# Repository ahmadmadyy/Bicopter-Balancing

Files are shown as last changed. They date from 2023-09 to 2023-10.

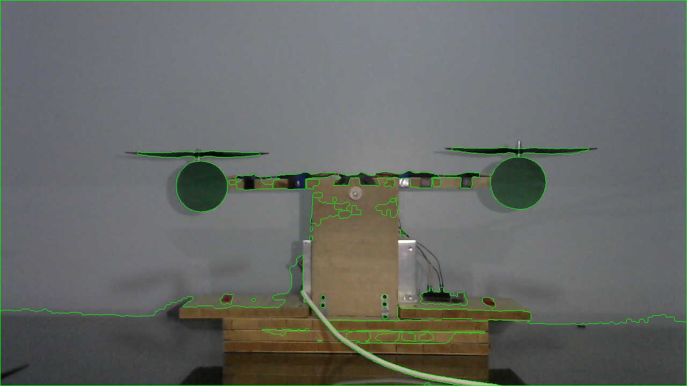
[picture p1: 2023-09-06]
Open Loop Tests/Tests on Camera and PC/Images/WATERSHED Segmentation.jpg

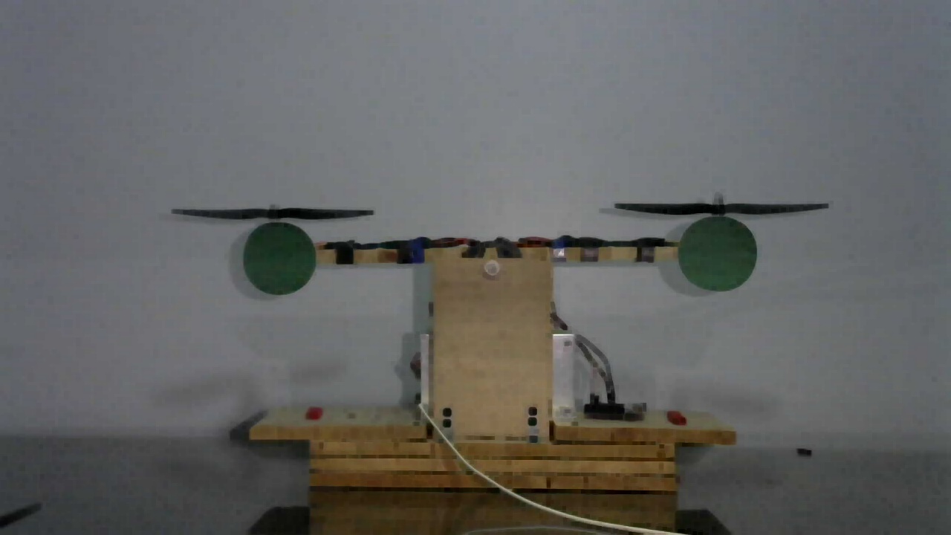
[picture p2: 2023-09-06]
Open Loop Tests/Tests on Camera and PC/Images/Erosion.jpg

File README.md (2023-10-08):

# Bicopter-Balancing
## A bicopter that uses a camera sensor and a computer vision algorithm in Python on an embedded Raspberry Pi 4 to balance a beam horizontally by actuating 2 BLDC Motors

#### The hardware consists of 2 BLDC Motors and a horizontal beam attached to their respective Electroic speed controllers(ESCs). After callibration, the 2 ESCs are connected to the raspberry pi 4, where the webcam camera sensor is connected, and using python and computer vision with some image processing techniques, the beam balanced.

#### In this repo, you can find the hardware design folder which contains all the Solidworks parts and assembly. In the open loops tests folder, you will find some python codes for applying image processing techniques on the captured images. In the closed loop folder, you will find the python codes for using the PID control on the raspberry pi. All technical detalis can be dound in the project report folder.

## Youtube Video:
Video (https://www.youtube.com/watch?v=bFz2ZuhfHQo)

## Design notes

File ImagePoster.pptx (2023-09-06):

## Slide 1

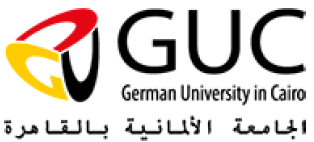
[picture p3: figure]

Image Processing for Mechatronics MCTR1010

Balancing a Brushless Bicopter using a Visual Sensor

Dr. Eng. Omar M. Shehata , Eng. Dalia M. Mahfouz, Eng. Mai Mira, MSc

Team Members:
Ahmed Mady 46-0798 ahmed.alimady@student.guc.edu.eg || Ahmed Yasser 46-12951 ahmed.yasser@student.guc.edu.eg ||Omar Mohsen 46-5023 omar.mohsen@student.guc.edu.eg Mostafa Kashaf 46-5456 mostafa.kashaf@student.guc.edu.eg || Mohamed Magdy 46-3493 mohamed.magdy@student.guc.edu.eg

Spring 2023

Abstract
The bicopter is a two-rotor aerial vehicle, characterized by its ability to maintain stable flight by actively adjusting the angle of its central bar horizontally. By leveraging the powerful computational capabilities and the versatility of the Raspberry Pi, the system achieves enhanced responsiveness and adaptability. The webcam captures images of the surrounding environment and processes them using image processing algorithms techniques such as edge detection is employed to identify the bicopter's central bar and determine its orientation relative to the horizontal plane. The integration of the Raspberry Pi and the webcam result in a robust and cost-effective solution for achieving self-balancing flight.

Results
Execution Time: On a Raspberry Pi 4B+, the average execution time of the code you provided is about 100 milliseconds. This means that the code can process one frame of video every 100 milliseconds. Accuracy: The accuracy of the code in detecting the angle of the bicopter is very high as the 2 motors never turn off but are always on and at varying speeds. Stability: The stability of the bi-copter was taken into consideration when designing the control law. Responsiveness: The responsiveness of the code to changes in the angle of the bicopter.

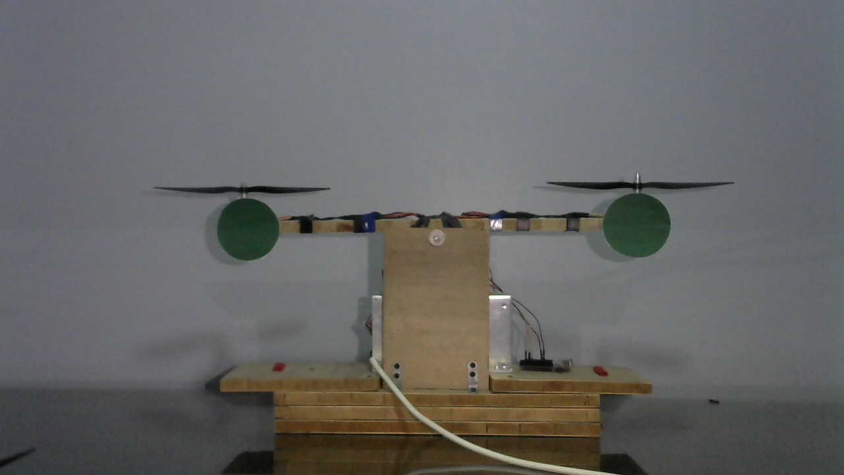
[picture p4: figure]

Methodology
To control the bicopter, a desired angle is inputted, and according to this angle, the speed of both motors is adjusted as they rotate in directions opposite to each other. Below each propeller, a colored circle is attached to track the error between the pitch and the desired angle using a visual sensor, the camera. The circles are of the color green and a threshold is applied to grab only the color needed. Then segmentation and edge detection were applied to track the circle and draw a line connecting both circles and measuring the angle. This measured error angle is then fed from the camera into the control loop as feedback and the correct speed is sent to the ESC of the two brush-less motors by the computer to achieve the desired angle.

Conclusion
The camera’s input is processed by the Raspberry Pi, which analyzes the images and extracts relevant features to estimate the bicopter’s position and orientation. This data is then fed into the PID control algorithm, which calculates the necessary adjustments to the bicopter’s motor speeds or control surfaces. The integration of these technologies enables autonomous or semi-autonomous flight of the bicopter. Overall, the combination of a camera, Raspberry Pi 4B+, and PID control offers a reliable and adaptable system for controlling a bicopter.

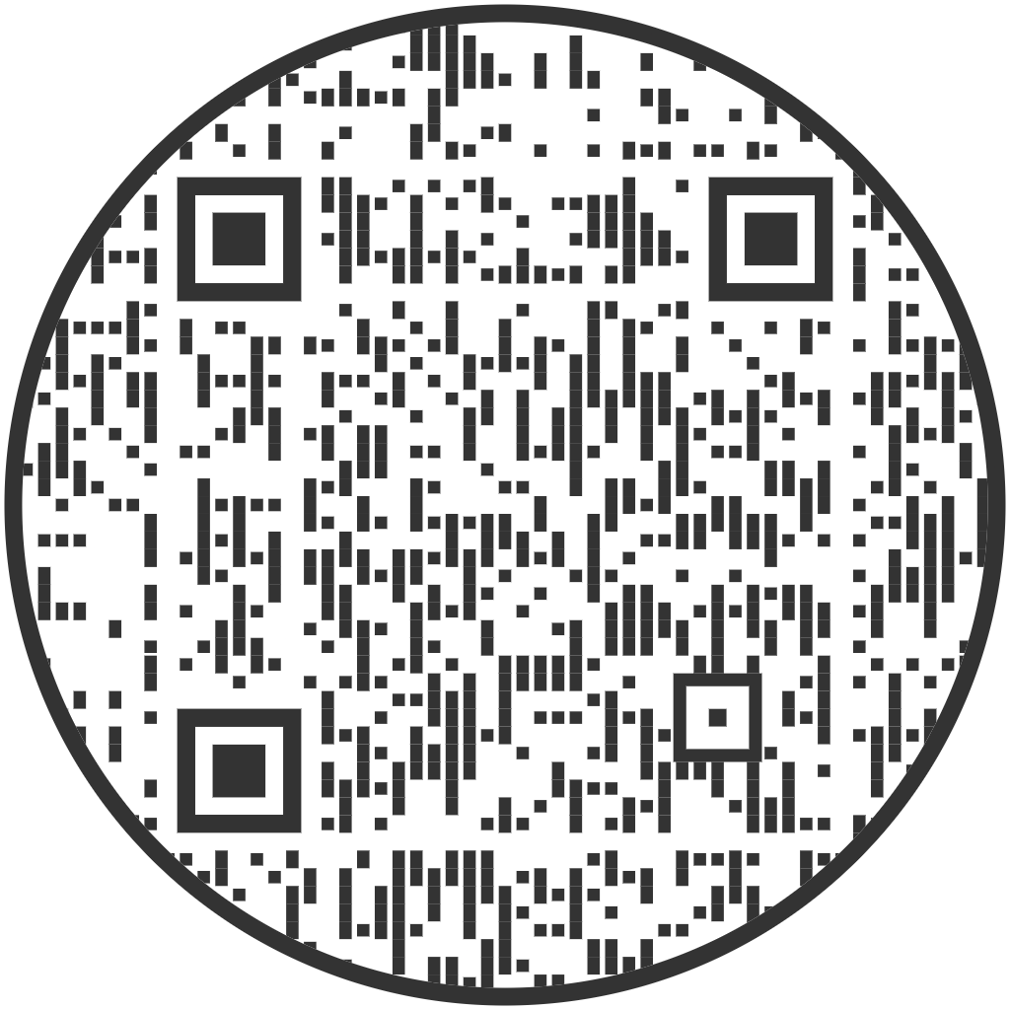
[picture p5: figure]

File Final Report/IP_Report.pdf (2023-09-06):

## Balancing a Brushless Bicopter using a Visual Sensor

Ahmed Mady, Ahmed Yasser, Omar Mohsen, Mostafa Kashaf, Mohammad Magdy

Abstract

The bicopter is a two-rotor aerial vehicle, characterized by its ability to maintain stable flight by actively adjusting the angle of its central bar horizontally. By leveraging the powerful computational capabilities and the versatility of the Raspberry Pi, the system achieves enhanced responsiveness and adaptability. The webcam captures images of the surrounding environment and processes them using image processing algorithms techniques such as edge detection is employed to identify the bicopter’s central bar and determine its orientation relative to the horizontal plane. The integration of the Raspberry Pi and the webcam result in a robust and cost-effective solution for achieving self-balancing flight.

I. INTRODUCTION
A flying vehicle is not a novel engineering product. Yet, the rapid growth of unmanned aerial vehicles (UAVs) has made a research on the subject of flying vehicles a global hotspot today. One of the difficult difficulties has been reducing the number of rotors in a rotor-type UAV. One of the examples with only two rotors is the bicopter. As compared to other typical rotor-type UAVs with more rotors, it has a longer flight time. A reduction in the number of rotors can reduce unit time power demand and, as a result, improve flight time. However, because of the complexity of the mathematical dynamics model, controlling a bicopter system is not a simple process. To maintain the desired trajectory, the designed controller must be capable of stabilizing the bicopter with an acceptable response time while also overcoming the oscillation effect. To accurately stabilize the bicopter, a camera is used to find the angle of inclination of the birotor.

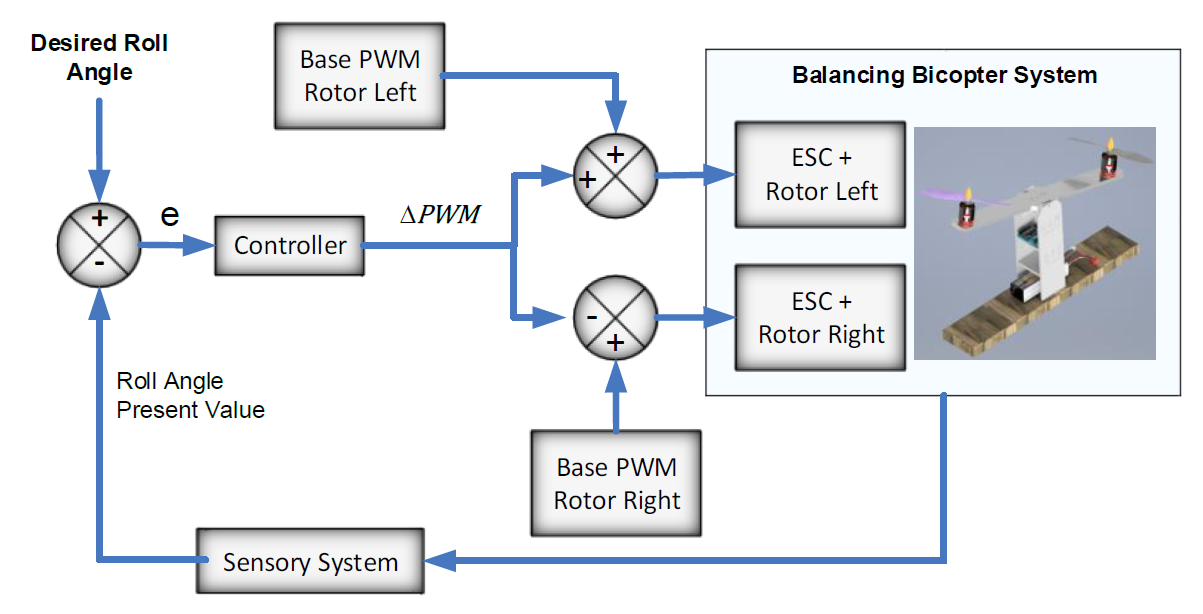
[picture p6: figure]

Fig. 1. The flow diagram of the system

II. METHODOLOGY

A. Workflow
To control the bicopter, a desired angle is inputted, and according to this angle, the speed of both motors is adjusted as they rotate in directions opposite to each other. Below each propeller, a colored circle is attached to track the error between the pitch and the desired angle using a visual sensor, the camera. The circles will be of the color blue and a threshold will be applied to grab only the color needed. Then segmentation and edge detection will be applied to track the circle and draw a line connecting both and measuring the angle. This measured error angle is then fed from the camera into the control loop as feedback and the correct speed is sent to the ESC by the computer of the two brush-less motors to achieve the required angle desired. Figure 1 shows the flow diagram of the bicopter system. The sensory system is the Sony Widescreen HD 720p webcam.
B. Components
C. Circuit Design
The schematic circuit diagram of the birotor system is shown in Figure 3 which consists of the two brushless motors, the two ESCs, the Arduino, and the power source. The camera is the feedback element and is connected to the computer directly. The flow of data, Figure ?? is first from the camera to the computer which applies the image processing algorithm which calculates the angle of the bicopter which is then sent to the Arduino using a USB connection and into the control loop. The Arduino then calculates the required speed of the motors.

TABLE I

LIST OF COMPONENTS

Component | Number | Purchase Location | Price
Raspberry Pi 4B | 1 | Future Electronics | 3370E£
Electronic Speed Controllers | 2 | Future Electronics | 205E£
Brushless Motor | 2 | Amazon Eg | 388E£
Propeller | 2 | Future Electronics | 150E£
12V 20A Power Source | 1 | Amazon Eg | 220E£
Sony Webcam | 1 | Amazon Eg | 599E£

Fig. 2. Solidworks Assembly 1

D. Image Processing

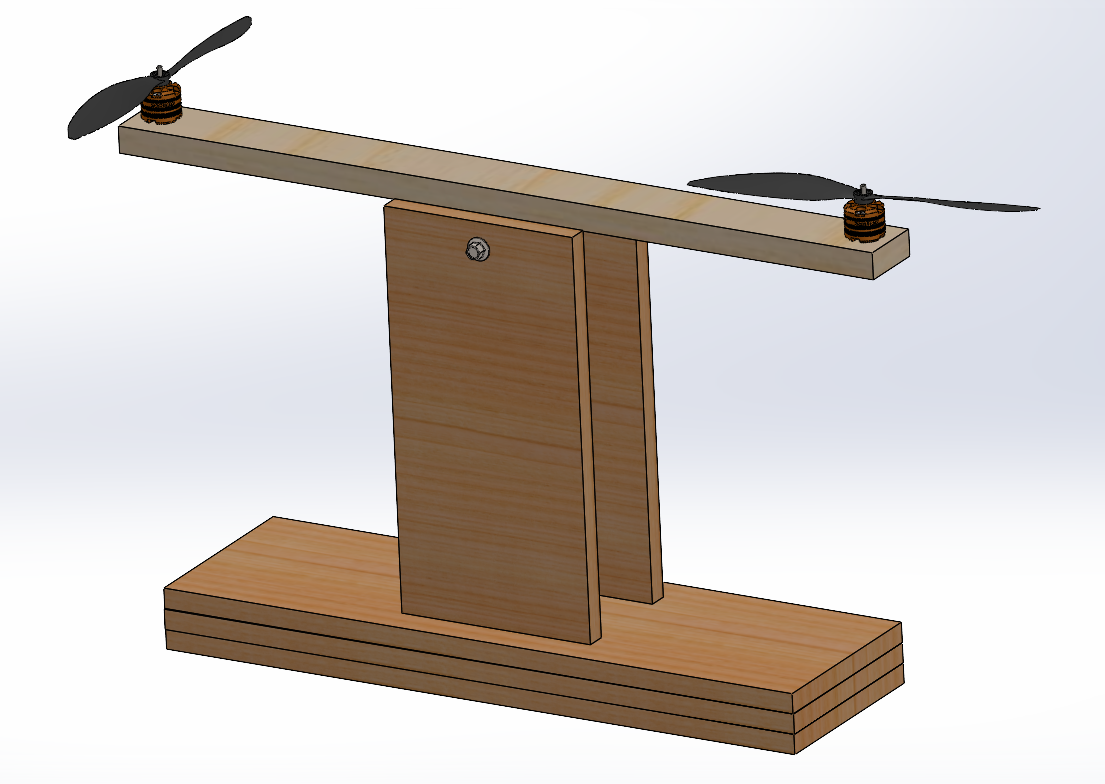
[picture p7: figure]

Image processing is the process of converting an image to a digital format and then executing various operations on it to extract valuable information. When specific specified signal processing methods are used, the image processing system typically interprets all images as 2D signals. The figure below 4 depicts the original photo taken by the camera prior to any image processing. Image processing tasks performed were translation and scaling, then converting the normal RBG image to LAB and HSV color spaces then grayscale where contrast enhancement and darkening were applied.
1) Intensity Level Transformation

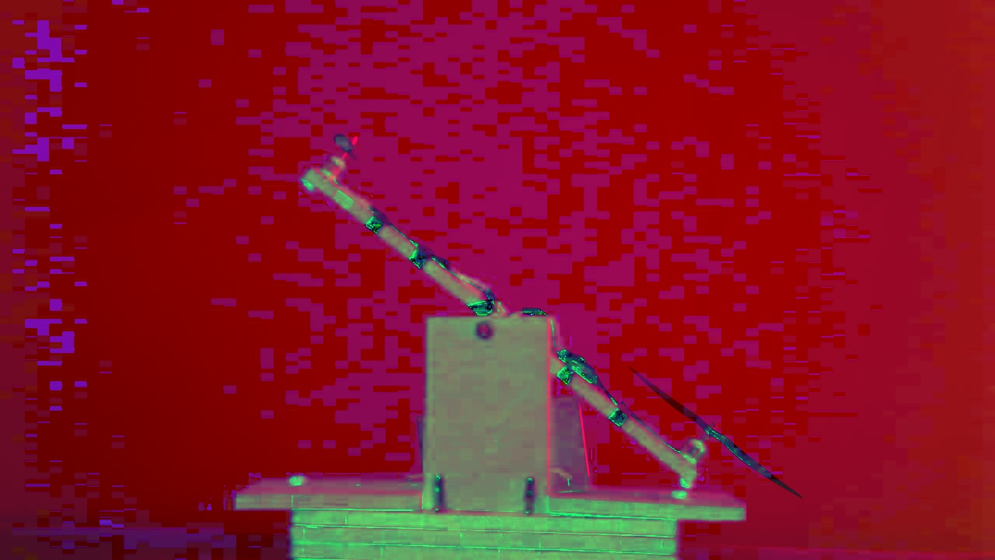
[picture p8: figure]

Fig. 5. The Image After Applying HSV Color Space

2) Morphological Operations
Morphological operations are a set of operations that process images based on shapes. They apply a structuring element to an input image and generate an output image.

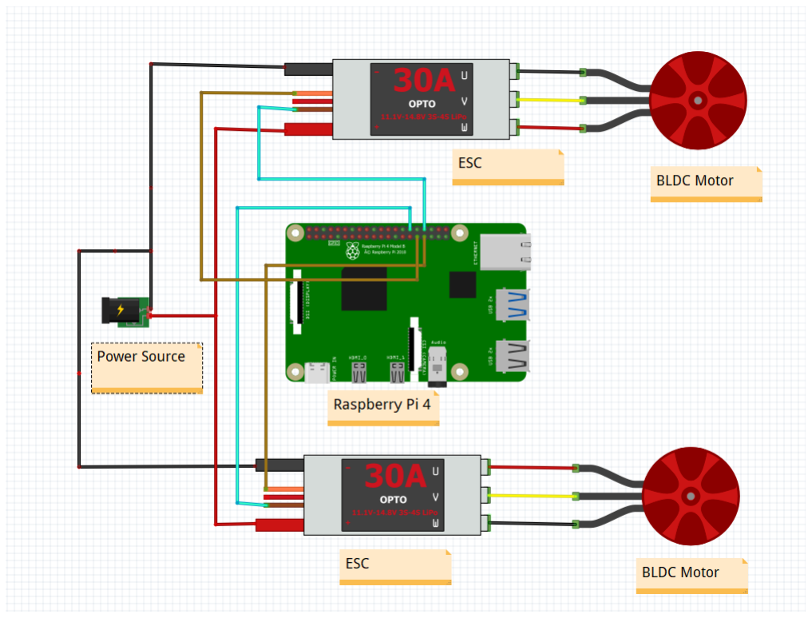
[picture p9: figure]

Fig. 3. Circuit diagram of the birotor system

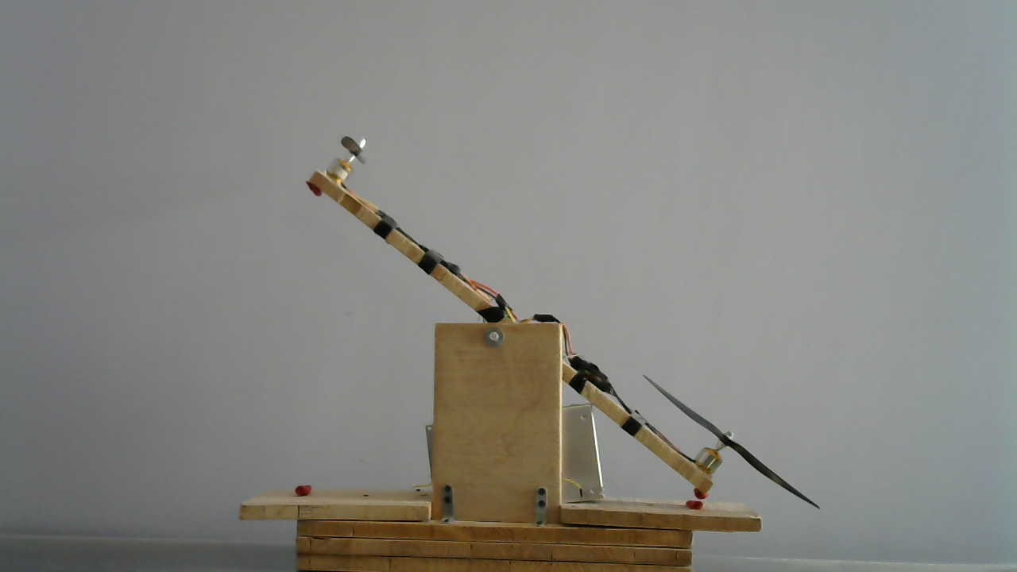
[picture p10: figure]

Fig. 4. Orignal Image before any transformations


Fig. 6. The original image after adding colored figures, circles, under each motor

Next, erosion and dilation are applied. Basics of Erosion: Erodes away the boundaries of the foreground object, Used to diminish the features of an image. Basics of dilation: Increases the object area, Used to accentuate features. Both are applied using a 5 x 5 kernel.


Fig. 7. The image after applying erosion using a 5 x 5 kernel

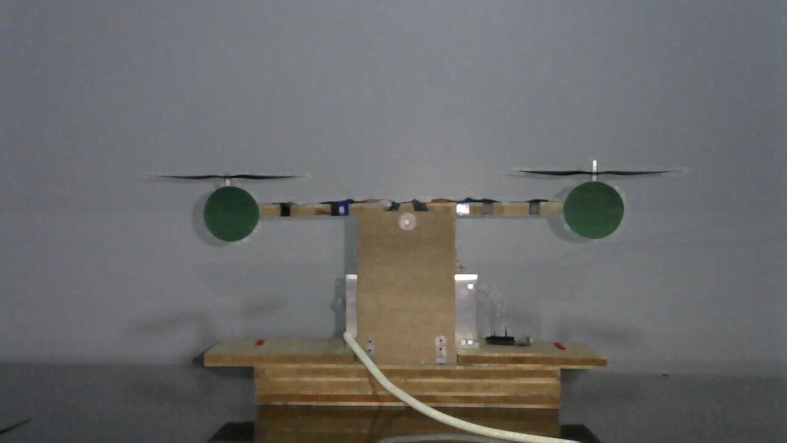
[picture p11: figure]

Fig. 8. The image after applying dilation using a 5 x 5 kernel

3) Edge Detection Edge detection is an image processing technique for finding the boundaries of objects within images. It works by detecting discontinuities in brightness. In this paper, edge detection is implemented using different methods applied on the, 5 x 5 Gaussian blurred image:
a) Canny Edge Detection

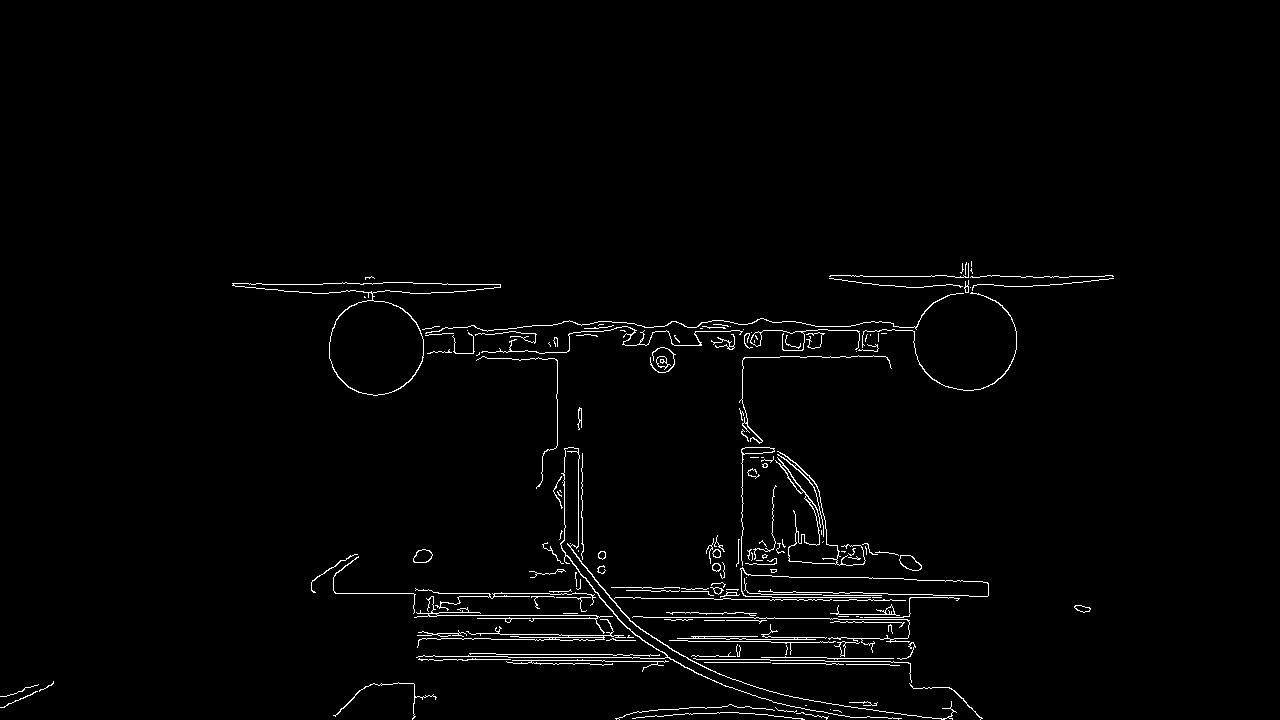
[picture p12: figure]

Fig. 9. The image after Canny edge detection using a threshold range 0 to 60

4) Segmentation
a) Color Segmentation The first type of segmentation applied was to color segment the green circle which will be used later for angle calculation.

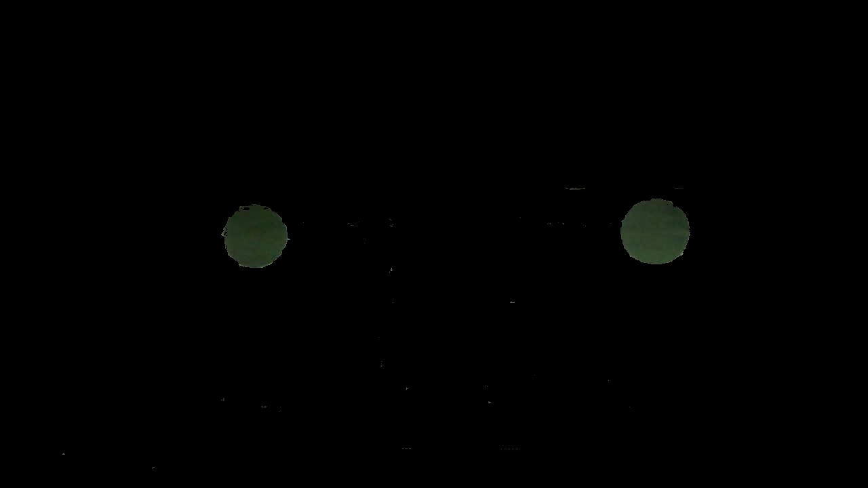
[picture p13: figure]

Fig. 10. The image after applying the green segmentation

b) Watershed Algorithm The watershed algorithm is used for segmentation in some complex images if we apply simple thresholding and contour detection then will not be able to give proper results. The watershed algorithm is based on extracting sure background and foreground and then using markers will make a watershed run and detect the exact boundaries. This algorithm generally helps in detecting touching and overlapping objects in the image. For markers, it can be user-defined like manually clicking and getting the coordinates and also using some defined algorithms such as thresholding or any morphological operations. Due to the presence of noise, we can’t apply watershed algorithms directly.


Fig. 11. The image after applying the watershed algorithm

E. Control
The dynamical equation is shown in Equation 1:

˙
˙θb =

M2 − M1 ∗ g ∗

L
2 − b

˙
θb − a

˙ θb(ωm2 + ωm1
) + 0.00125L ∗ (ωm2 + ωm1

)
MomentofInertia | (1)

T ransferF unction :

0.6126s

3 − 1.359s

2 + 28.81s + 5.315
s

4 + 2.27s

3 + 19.89s

2 + 14.84s + 2.74

(2)

After manually tuning the PID the final values reached were:

kp = 1, ki = 2, kd = 0.3 | (3)

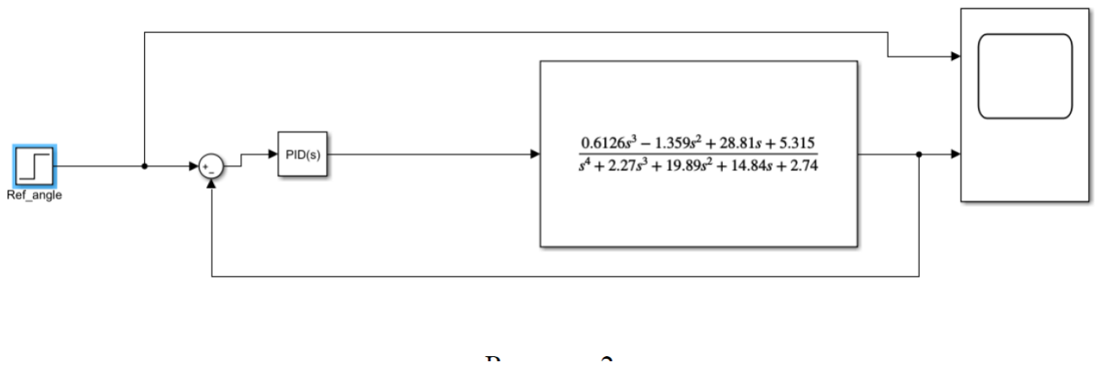
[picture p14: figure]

Fig. 12. SIMULINK simulation of the transfer function

a) Closed Loop Response In this section, a simple closed loop is tested. Python communicates with Arduino to send a control action to the 2 BLDC motors based on the image processing signal by establishing a serial communication. First in the image processing code in python, the frame captures from the external camera then converts the frame into gray-scale. After converting, numpy mean method is used to calculate the average of the intensity levels of the pixels in the image. If the pixels have a mean higher than 100, also called a bright frame, the left motor is actuated based on a signal given from python to the Arduino. If the mean is less than 50, dark frame, the right motor is actuated.
F. Actuation
At the beginning of the code, the libraries are imported. Then, the ranges of green color are HSV are defined from low to the max values based on trial and error which then applies a mask to detect only green color on the video capture frame which in turn is used to detect only the largest 2 circles only of green colors. The centers of the circles are used then to calculate the slope of the bi copter bar which is our error signal. This error signal is taken as input to the PID controller and then taken as input to the PWM output to the motor.

III. RESULTS
The results of this study show that it is possible to balance a bicopter around a zero angle using a camera and a Raspberry Pi. The system was able to maintain a stable hover for up to 30 seconds, even in the presence of disturbances. The system was also able to track the moving target circles, such as a person’s head, and maintain a balancing angle.
A. KPIs
Execution Time: On a Raspberry Pi 4B+, the average execution time of the code you provided is about 100 milliseconds. This means that the code can process one frame of video every 100 milliseconds. Accuracy: The accuracy of the code in detecting the angle of the bicopter is very high as the 2 motors never turn off but are always on and at varying speeds. Stability: The stability of the bi-copter was taken into consideration when designing the control law. Responsiveness: The responsiveness of the code to changes in the angle of the by-copter.

IV. CONCLUSION
In conclusion, the utilization of a camera and Raspberry Pi 4B+ in combination with PID control provides an effective solution for controlling a bicopter. By leveraging the camera’s ability to capture real-time images and the Raspberry Pi’s processing power, the system can extract essential information about the bicopter’s orientation and position. This information is then used to calculate appropriate control signals using PID control algorithms, ensuring stable and precise flight.
The camera’s input is processed by the Raspberry Pi, which analyzes the images and extracts relevant features to estimate the bicopter’s position and orientation. This data is then fed into the PID control algorithm, which calculates the necessary adjustments to the bicopter’s motor speeds or control surfaces.
PID control provides a robust and widely used method for adjusting control signals based on the error between desired and measured values. It continuously evaluates and adjusts the output to minimize this error, resulting in smooth and accurate control of the bicopter.
The integration of these technologies enables autonomous or semi-autonomous flight of the bicopter. It opens up possi-bilities for various applications, such as aerial surveillance, monitoring, and inspection tasks. Additionally, the flexibility of the Raspberry Pi platform allows for easy customization and expansion, facilitating the implementation of advanced features and functionalities.
Overall, the combination of a camera, Raspberry Pi 4B+, and PID control offers a reliable and adaptable system for controlling a bicopter. It represents a promising avenue for further exploration and development in the field of unmanned aerial vehicles and autonomous systems.

V. VIDEOS

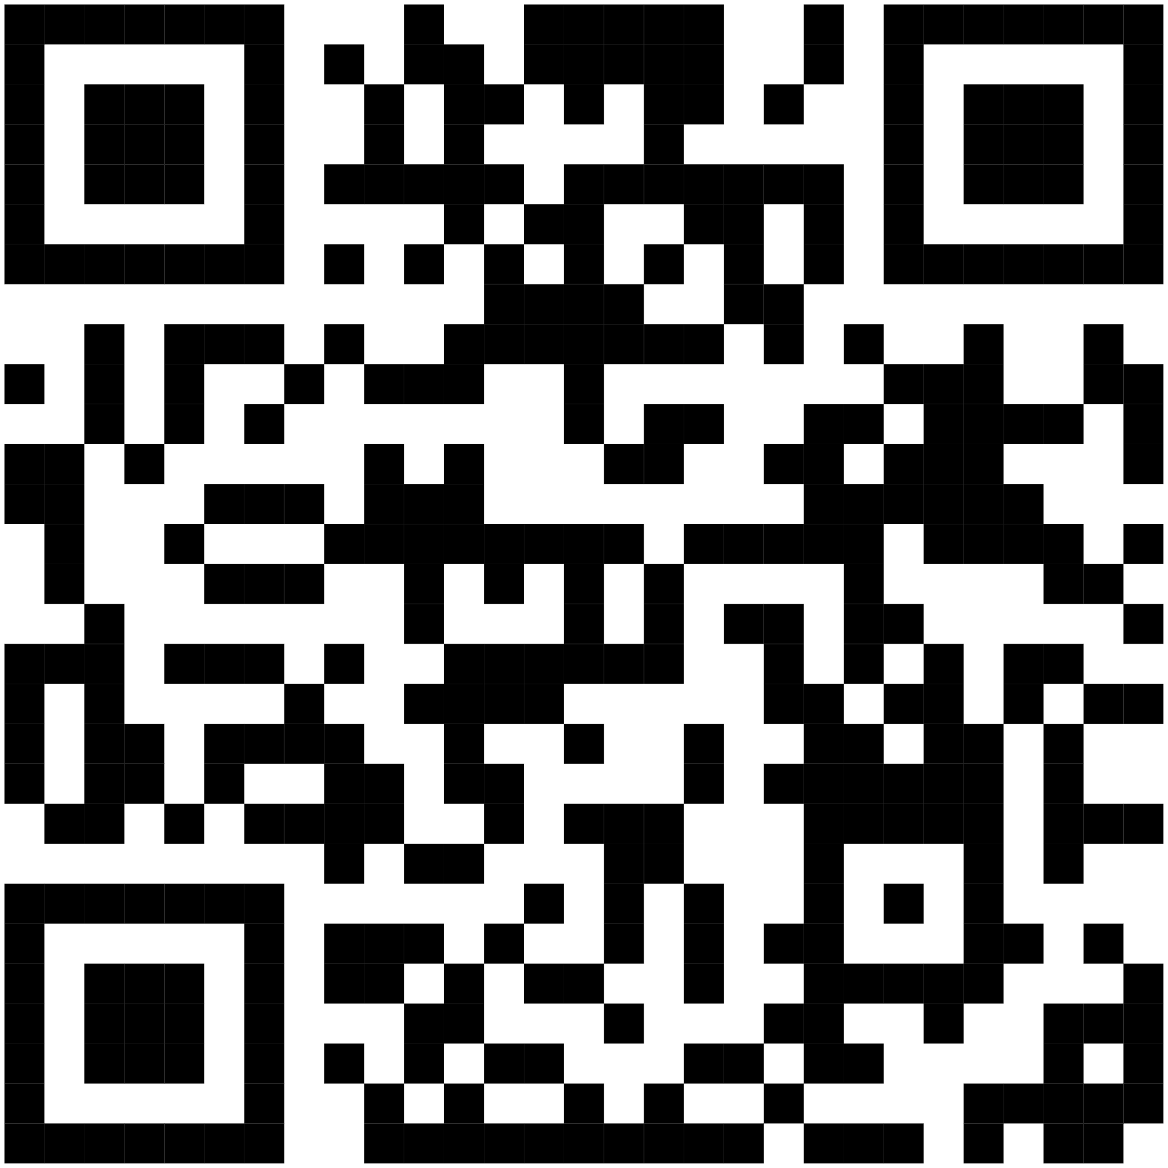
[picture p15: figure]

Fig. 13. QR Code containing the videos of the hardware

REFERENCES

[1] Apriaskar, E., Fahmizal, F., Salim, N. A., & Prastiyanto, D. (2019). Performance Evaluation of Balancing Bicopter using P, PI, and PID Controller. Jurnal Teknik Elektro, 11(2), 44-49.
[2] Siddhartha, K. (2018). A novel bi-rotor configuration and its control. IFAC-PapersOnLine, 51(1), 456-461.
[3] Qin, Y., Xu, W., Lee, A., & Zhang, F. (2020). Gemini: A compact yet efficient bi-copter uav for indoor applications. IEEE Robotics and Automation Letters, 5(2), 3213-3220.
[4] Jain, P., & Sangwan, V. (2020, July). Generation and Control of Impulsive Forces by a Planar Bi-Rotor Aerial Vehicle through a Cable Suspended Mass. In 2020 IEEE/ASME International Conference on Advanced Intelligent Mechatronics (AIM) (pp. 868-873). IEEE.
[5] Li, Y., Qin, Y., Xu, W., & Zhang, F. (2020, July). Modeling, identification, and control of non-minimum phase dynamics of bi-copter uavs. In 2020 IEEE/ASME International Conference on Advanced Intelligent Mechatronics (AIM) (pp. 1249-1255). IEEE.
[6] Ugurlu, H. ˘

˙I. (2019). A Comparative Study of learning-based control policies and conventional controllers on 2D bi-rotor platform with tail assistance (Master’s thesis, Middle East Technical University).
[7] Taherinezhad, M., Ramirez-Serrano, A., & Abedini, A. (2022). Robust trajectory-tracking for a bi-copter drone using indi: A gain tuning multi-objective approach. Robotics, 11(5), 86.
[8]

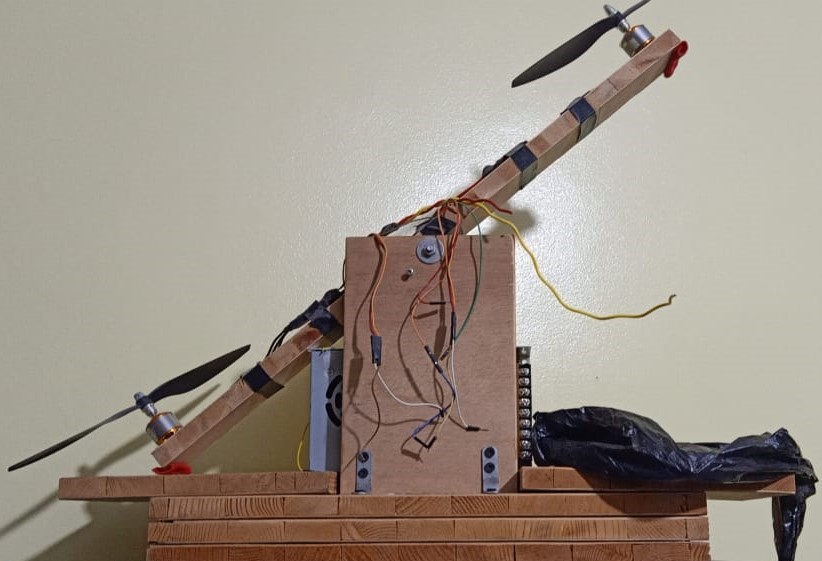
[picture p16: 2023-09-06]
Open Loop Tests/Pics/Hardware.jpg

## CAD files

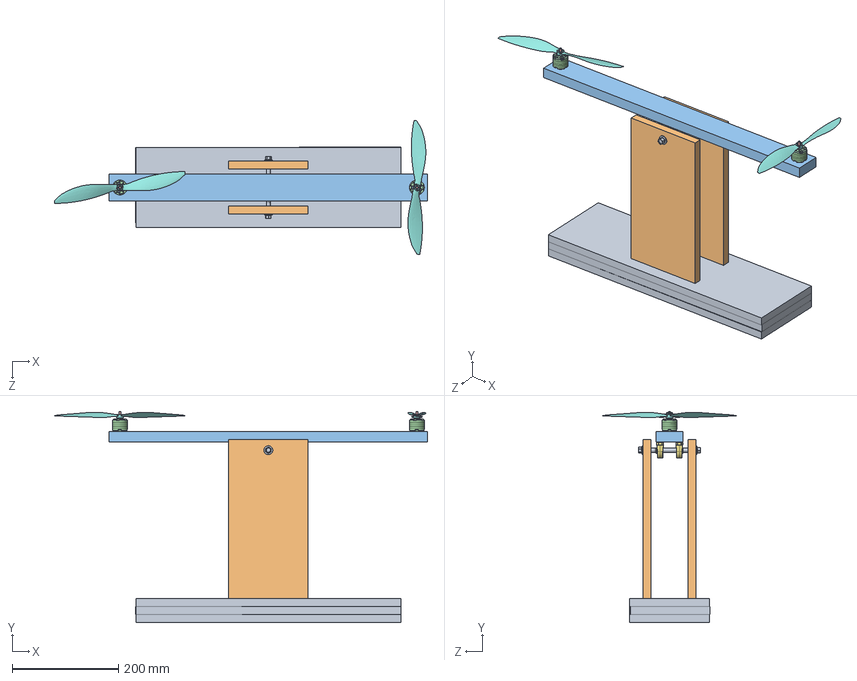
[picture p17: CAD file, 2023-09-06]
Hardware Design/Bicopter Assembly.SLDASM
703.2 x 398.0 x 253.4 mm
Base x 3
Front and Back x 2
Bar
ROTOR x 4
bldc motor shaft x 2
radial ball bearing_68_skf x 4
Bearing (KP08) x 2
10x4.7-clockwise-propeller x 2
indented hex flange head machine screw_am x 2

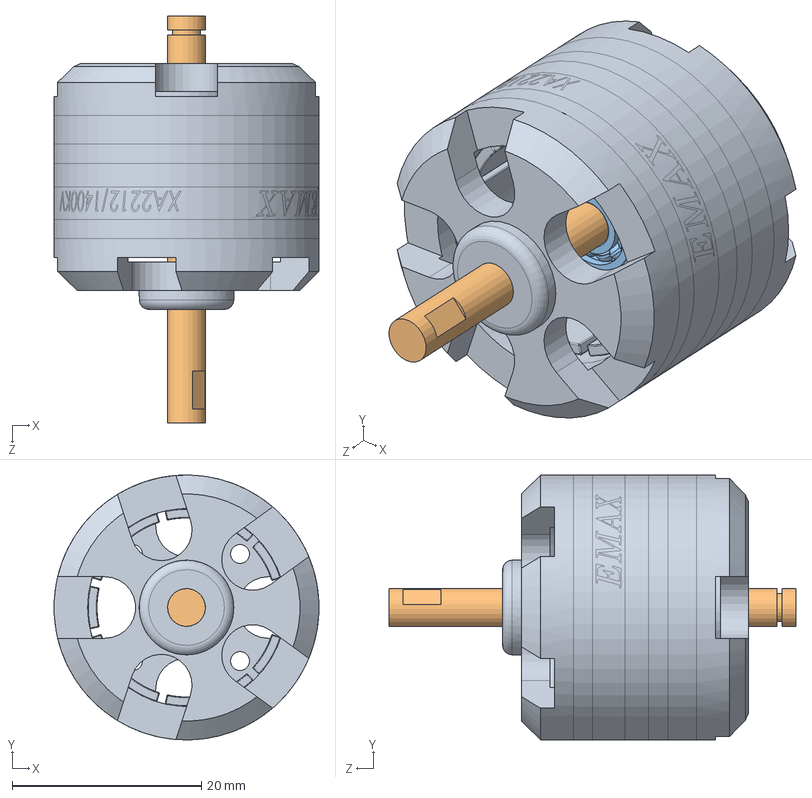
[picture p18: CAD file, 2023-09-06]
Hardware Design/a2212-brushless-dc-motor.SLDASM
28.0 x 28.0 x 43.0 mm
ROTOR x 2
bldc motor shaft
radial ball bearing_68_skf x 2

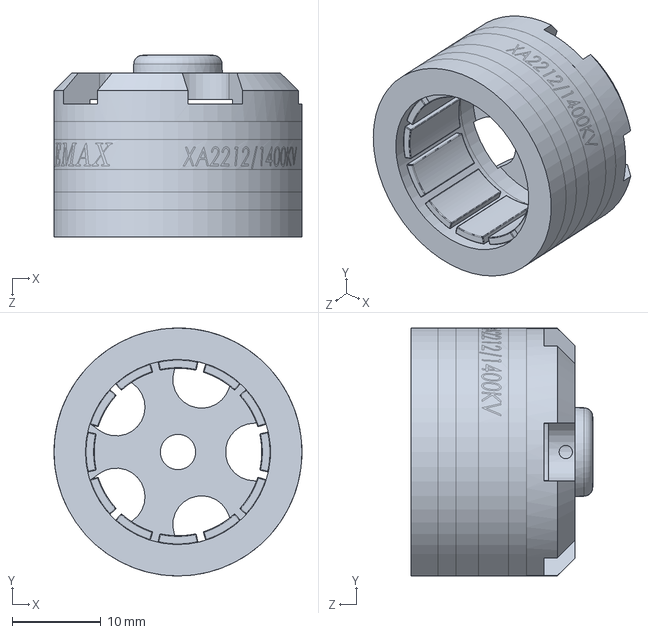
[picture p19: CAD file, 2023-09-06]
Hardware Design/ROTOR.SLDPRT
28.0 x 28.0 x 20.5 mm

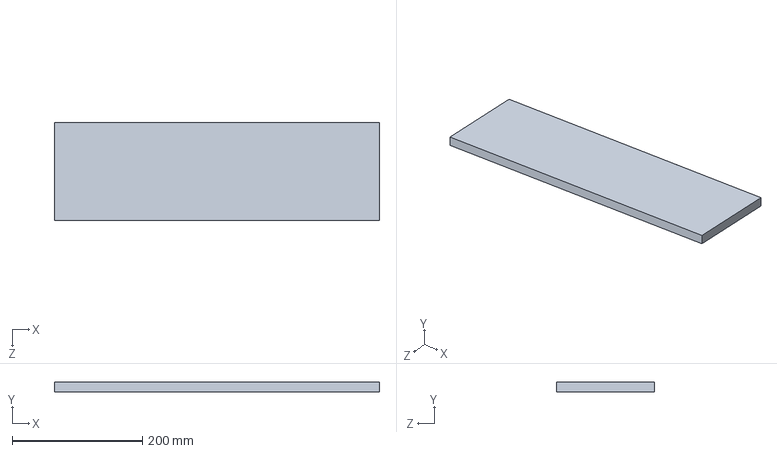
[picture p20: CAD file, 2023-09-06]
Hardware Design/Base.SLDPRT
500.0 x 15.0 x 150.0 mm

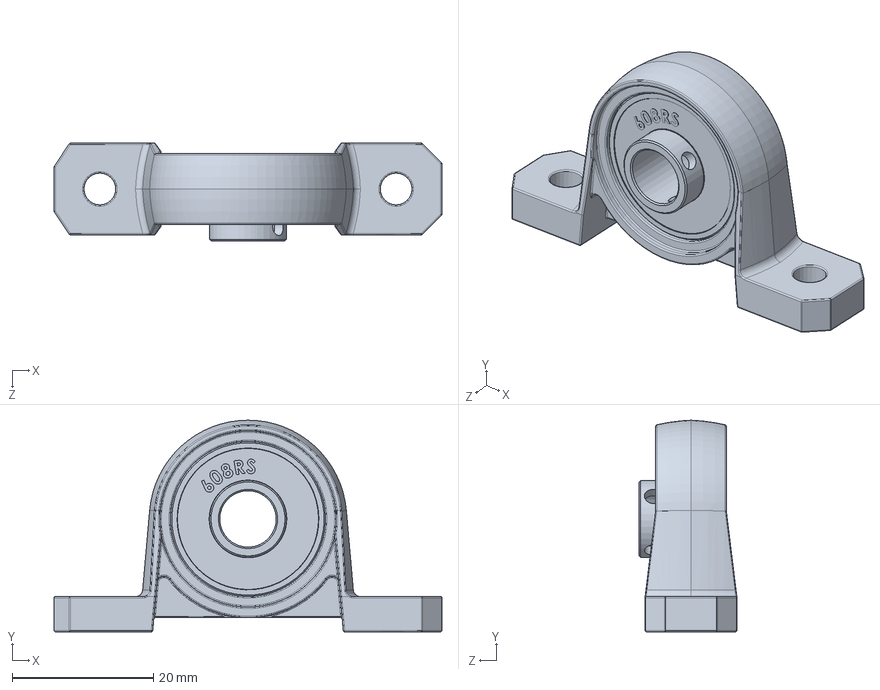
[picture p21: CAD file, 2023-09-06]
Hardware Design/Bearing (KP08).SLDPRT
55.0 x 30.0 x 13.9 mm

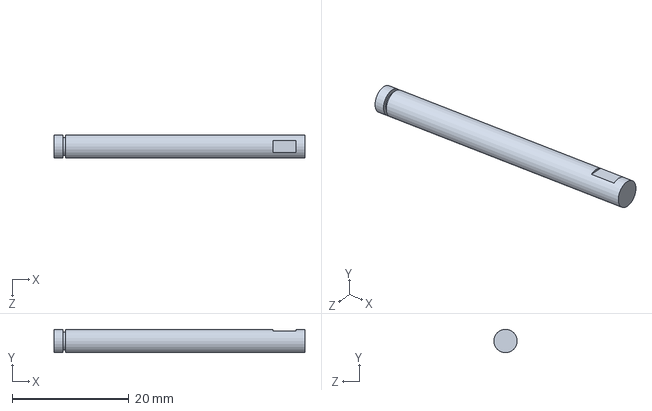
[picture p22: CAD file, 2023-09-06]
Hardware Design/bldc motor shaft.SLDPRT
43.0 x 4.00 x 4.00 mm

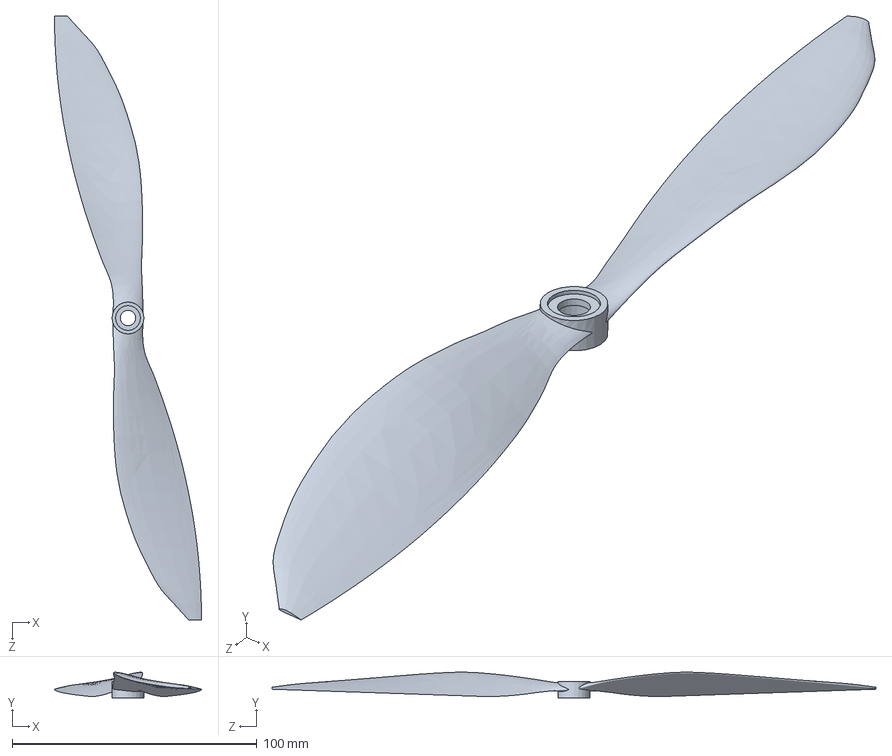
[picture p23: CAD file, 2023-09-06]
Hardware Design/10x4.7-clockwise-propeller.SLDPRT
60.0 x 10.5 x 246.4 mm

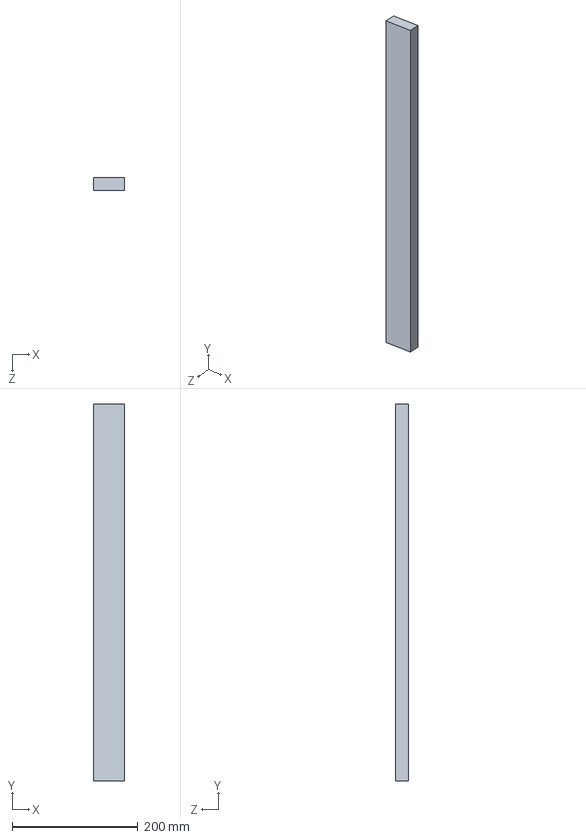
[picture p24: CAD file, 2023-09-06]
Hardware Design/Bar.SLDPRT
50.0 x 600.0 x 20.0 mm

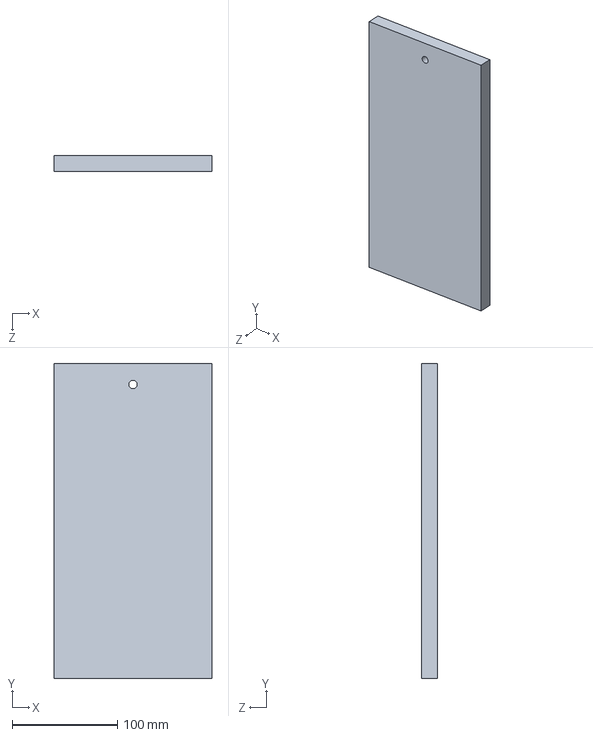
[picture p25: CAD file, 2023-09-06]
Hardware Design/Front and Back.SLDPRT
150.0 x 300.0 x 15.0 mm

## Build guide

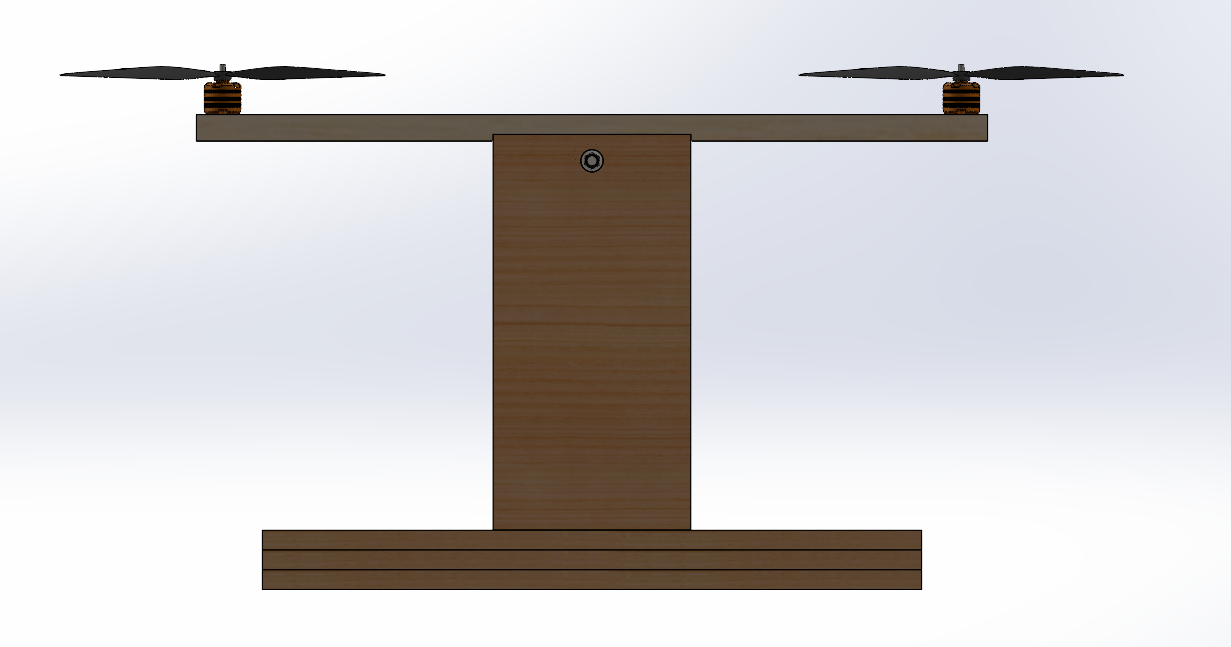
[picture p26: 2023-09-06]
Open Loop Tests/Pics/PICS/assembly2.png

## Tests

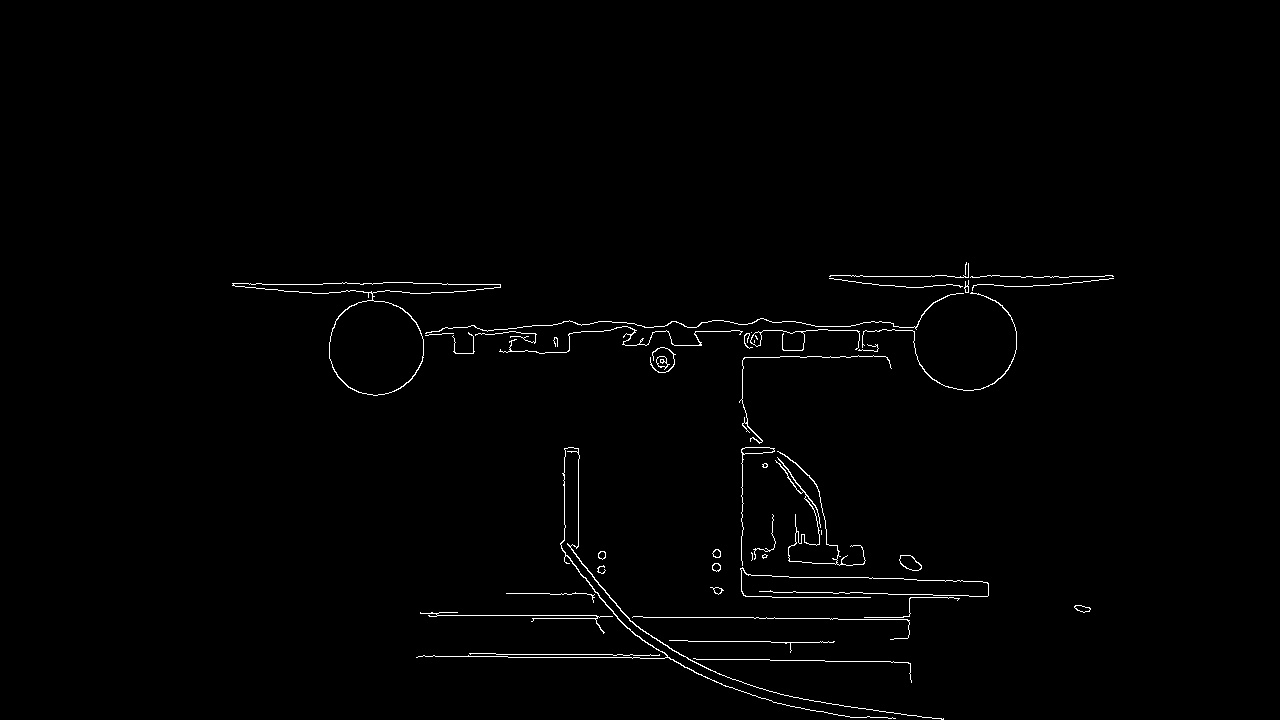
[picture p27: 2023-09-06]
Open Loop Tests/Tests on Camera and PC/Images/MidCanny.jpg

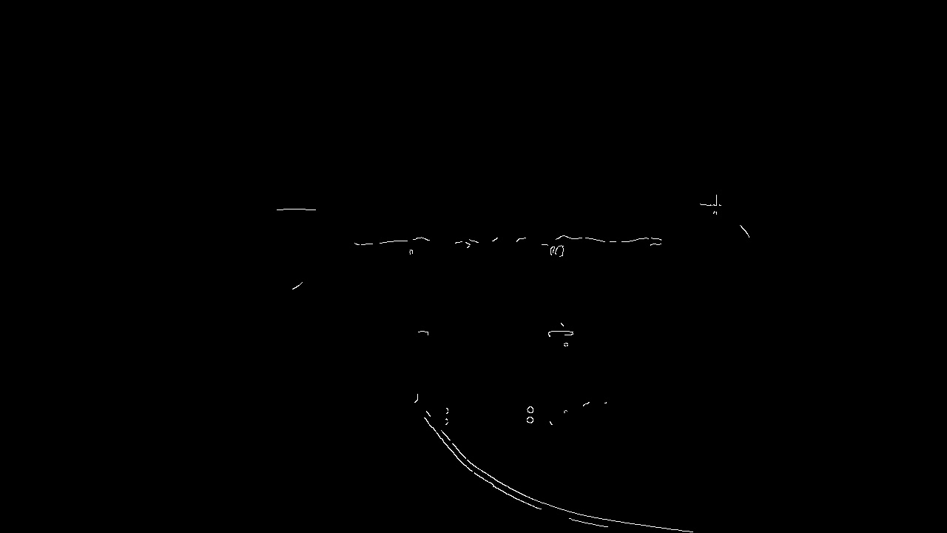
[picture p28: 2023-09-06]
Open Loop Tests/Tests on Camera and PC/Images/TightCanny.jpg

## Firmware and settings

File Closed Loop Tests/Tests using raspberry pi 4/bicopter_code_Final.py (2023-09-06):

#sudo killall pigpiod
import cv2
import os     #importing os library so as to communicate with the system
import time   #importing time library to make Rpi wait because its too impatient
sudoPassword='madypi'
command='killall pigpiod'
p=os.system('echo %s|sudo -S %s' % (sudoPassword, command))
os.system ("sudo pigpiod") #Launching GPIO library
#os.popen ("sudo -S %s"(sudo killall pigpiod),'w').write('madypi') #Launching GPIO library
time.sleep(1) # As i said it is too impatient and so if this delay is removed you will get an error
import pigpio #importing GPIO library
import numpy as np
import math

CURRENT_OPENCV_BUILD_VERSION = [4, 4, 0]
ESCR=19
#Connect the ESC in this GPIO pin
ESCL=13  #Connect the ESC in this GPIO pin

piR = pigpio.pi();
piL = pigpio.pi();
piR.set_servo_pulsewidth(ESCR, 1000)
piL.set_servo_pulsewidth(ESCL, 1000)
time.sleep(1)
cap = cv2.VideoCapture(0) # You may need to change the camera index depending on your system
startTime=0
throttle=1080
timee=time.time()

integralVal=0
e=0
loopDuration=0
prevDuration=0
u=0
prev_e=0

kp=0.88#3.3#0.83----0.88
ki=0.001
kd=0.55#1.7#0.36
global angle
angle=0.0
def image_Angle():
    ret, frame = cap.read()
     # Adaptive Thresholding
#     gray = cv2.cvtColor(frame, cv2.COLOR_BGR2GRAY)q
#     mean = np.mean(gray)
#     if mean < 100:
#         frame = cv2.convertScaleAbs(frame, alpha=70, beta=0)
#     elif mean > 200:
#         frame = cv2.convertScaleAbs(frame, alpha=0.5, beta=0)
    # Convert the frame to HSV color space
    hsv = cv2.cvtColor(frame, cv2.COLOR_BGR2HSV)
    # at a distance of 76 cm
    # White Lighting HSV
#     lower_green = np.array([40, 50, 50])
#     upper_green = np.array([80, 255, 255])
    # Yellow Lighting HSV
#    lower_green = np.array([90, 50, 50]) # 93
#    upper_green = np.array([100, 255, 255]) # 94
    lower_green = np.array([70, 60, 60])
    upper_green = np.array([80, 255, 255])
    
    # Threshold the HSV image to get only green colors
    mask = cv2.inRange(hsv, lower_green, upper_green)
    kernel = np.ones((9, 9), np.uint8)
    mask = cv2.morphologyEx(mask, cv2.MORPH_CLOSE, kernel)
    
    # Find contours in the binary image
    contours, hierarchy = cv2.findContours(mask, cv2.RETR_EXTERNAL, cv2.CHAIN_APPROX_SIMPLE)
    
    # Draw circles around the detected contours and calculate their centers
    centers = []
    for cnt in contours:
        (x, y), radius = cv2.minEnclosingCircle(cnt)
        diameter = radius * 2
        center = (int(x), int(y))
        if diameter >= 50: # Only consider circles with a diameter greater than or equal to 100 pixels
            cv2.circle(frame, center, int(radius), (0, 255, 0), 2)
            centers.append(center)
    
    # Calculate the angle between any two detected centers
    if len(centers) == 2:
        for i in range(len(centers)-1):
            for j in range(i+1, len(centers)):
                center1 = centers[i]
                center2 = centers[j]
                dx = center2[0] - center1[0]
                dy = center2[1] - center1[1]
                global angle
                angle = math.atan(dy/dx) * 180 / np.pi
                angle = round(angle,1)
                cv2.putText(frame, f"Angle: {angle:.2f} deg", (50, 50), cv2.FONT_HERSHEY_SIMPLEX, 1, (255, 0, 0), 2)


    
#     # Display the resulting frame
    scale_percent = 90# percent of original size
    width = int(frame.shape[1] * scale_percent / 100)
    height = int(frame.shape[0] * scale_percent / 100)
    dim = (width, height)

    resized = cv2.resize(frame, dim, interpolation = cv2.INTER_AREA)
#   gray = cv2.cvtColor(frame, cv2.COLOR_BGR2GRAY)
    
    cv2.imshow('frame', resized)
    return

def check_build_info():
    success = True

    print("OpenCV Version: {}".format(cv2.__version__))
    if (cv2.getVersionMajor() != CURRENT_OPENCV_BUILD_VERSION[0]) and (
            cv2.getVersionMinor() != CURRENT_OPENCV_BUILD_VERSION[1]) and (
            cv2.getVersionRevision() != CURRENT_OPENCV_BUILD_VERSION[2]):
        print("ERROR: OpenCV version is different than the expected.")
        success = False

    print("Available CPUs: ", cv2.getNumberOfCPUs())
    print("Available threads: ", cv2.getNumThreads())
    if cv2.getNumThreads() < cv2.getNumberOfCPUs():
        print("ERROR: TBB is not enabled.")
        success = False

    cv2.CPU_NEON = 100  # Value taken from OpenCV doc. CPU labels don't work correctly in Python
    print("Cpu NEON support: ", cv2.checkHardwareSupport(cv2.CPU_NEON))
    if not cv2.checkHardwareSupport(cv2.CPU_NEON):
        print("ERROR: NEON is not enabled.")
        success = False

    return success
if not check_build_info():
    print("FAIL: You are using OpenCV without NEON/TBB support enabled.")
    sys.exit(1)
print("SUCCESS: You are using latest OpenCV version, with NEON/TBB support enabled.")
i=0
desired=0
while True:
    image_Angle()

       prevDuration = timee
       timee = time.time()
       loopDuration = (timee - prevDuration)
       e = angle - desired

       if (-20 < e < 20):
           integralVal = integralVal + (ki * e)

       u = (kp * e) + integralVal + (kd * ((e - prev_e) / loopDuration))
        
       if (u < -1000):
           u = -1000

       if (u > 1000):
           u = 1000

       round(throttle,0)
       leftSignal = throttle + u+60
       rightSignal = throttle - u

       #Right
       if (rightSignal < 1090):
           rightSignal = 1090
        
       if (rightSignal > 2000):
           rightSignal = 2000
        
       #Left
       if (leftSignal < 1100):
           leftSignal = 1100
        
       if (leftSignal >= 2000):
           leftSignal = 2000
        
       piR.set_servo_pulsewidth(ESCR, rightSignal)
       piL.set_servo_pulsewidth(ESCL, leftSignal)
        
       prev_e = e
        
       if cv2.waitKey(1) == ord('q'):
           piR.set_servo_pulsewidth(ESCR, 1000)
           piL.set_servo_pulsewidth(ESCL, 1000)
           break
    
cap.release()
cv2.destroyAllWindows()

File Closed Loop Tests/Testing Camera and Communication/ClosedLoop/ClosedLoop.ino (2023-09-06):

#include <Servo.h>
Servo right_Esc;
Servo left_Esc;
float loopDuration, time, prevDuration;
float u, leftSignal, rightSignal, e, prev_e;
float integralVal=0;
double throttle=1030 ; 

void setup() {
  Serial.begin(115200);
  right_Esc.attach(3); 
  left_Esc.attach(5); 
  time = millis(); 
  left_Esc.writeMicroseconds(1000); 
  right_Esc.writeMicroseconds(1000);
  delay(7000); 
  }

void loop() {
    if (Serial.available() > 0) {
    char num = Serial.read();
    if(num=='A')
    {
      left_Esc.writeMicroseconds(1060);
      delay(3000);
    }
    if(num == 'B')
    {
      right_Esc.writeMicroseconds(1060);
      delay(3000);
    }
    //left_Esc.writeMicroseconds(1060);
    //right_Esc.writeMicroseconds(1065);
   delay(2000);
}
}
